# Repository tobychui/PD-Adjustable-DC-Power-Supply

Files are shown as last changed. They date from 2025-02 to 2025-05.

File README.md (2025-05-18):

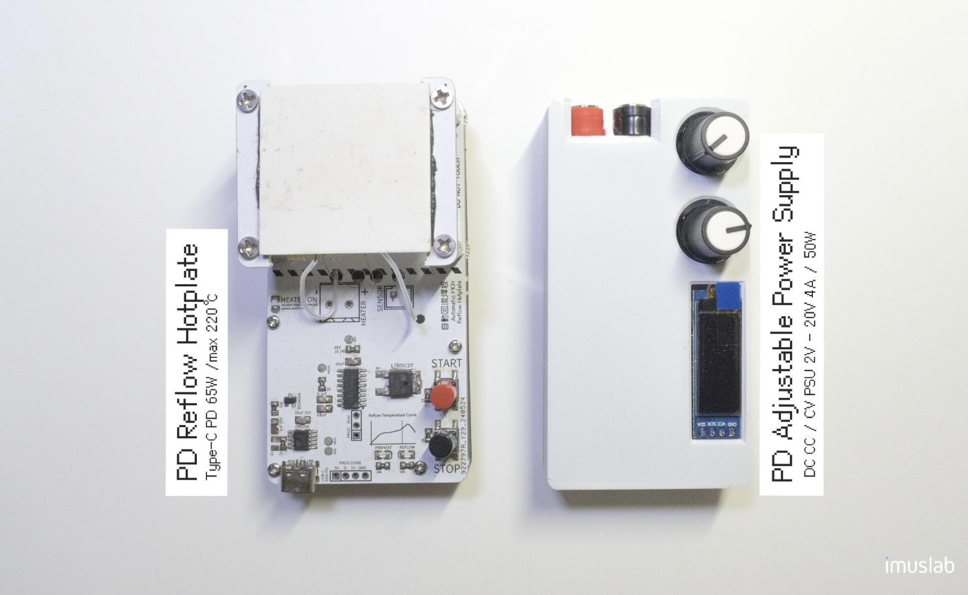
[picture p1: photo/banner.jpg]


# PD Adjustable DC Power Supply

A DIY, USB PD powered, pocket sized adjustable DC / lab bench power supply for electronic makers

I also made a pocket size reflow hotplate for automatically reflowing SMD components. See [here](https://github.com/tobychui/MCH-PD-Automatic-Reflow-Hotplate) for more details on how to build one. These two pocket size devices have the same footprint so they can be stacked in your portable tool box!

### Specifications

| Item | Value | Remarks |
| --- | --- | --- |
| Power Input | USB PD (type C) 60W at 20V 3A | Refer to CH224K datasheet for trigger specifications |
| Power Output | Adjustable DC (2V to 20V), max 4A or 50W | Refer to XL4015E datasheet for specification |
| Dimension | 10cm x 5.2cm x 1.9cm (without knobs)<br />10cm x 5.2cm x 3.3cm (with knobs) | Adj. Knobs are replaceable |
| Output Mode | Constant Voltage (CV) / Constant Current (CC) | |
| Display Size | 0.91 inch OLED | |
| Display Accuracy | +/- 0.02V and +/- 0.05A | Refresh rate @ 1Hz |
| Data Output | Real-time voltage and current usage in csv format | Can be viewed via Arduino IDE serial graph plotter |

### Photo

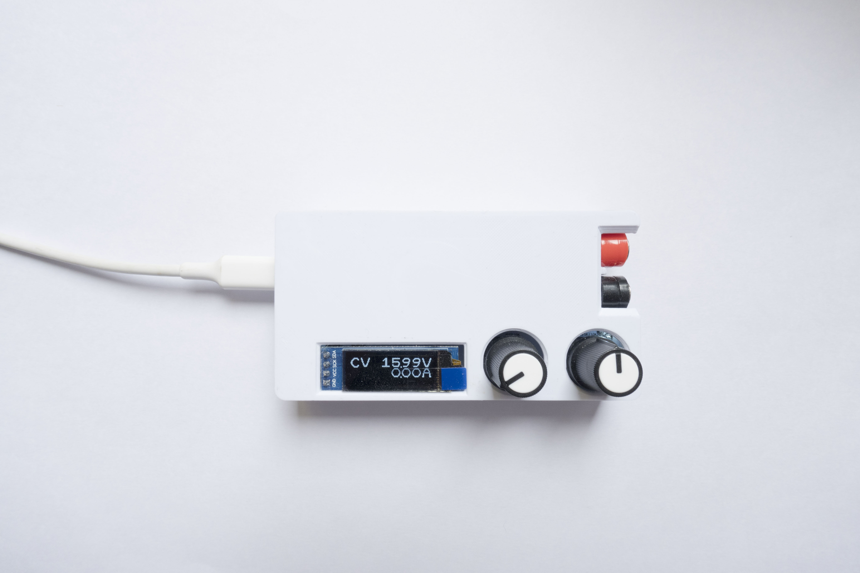
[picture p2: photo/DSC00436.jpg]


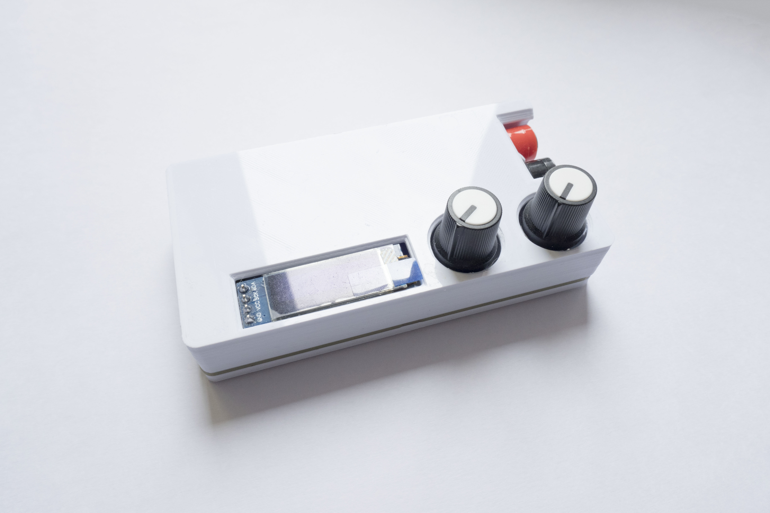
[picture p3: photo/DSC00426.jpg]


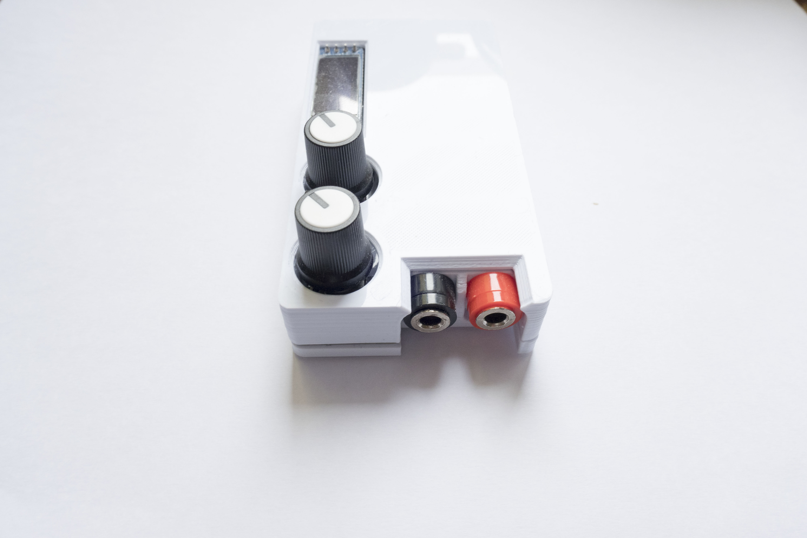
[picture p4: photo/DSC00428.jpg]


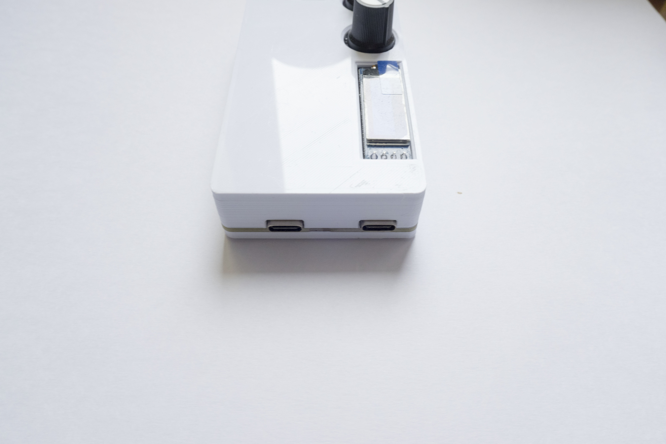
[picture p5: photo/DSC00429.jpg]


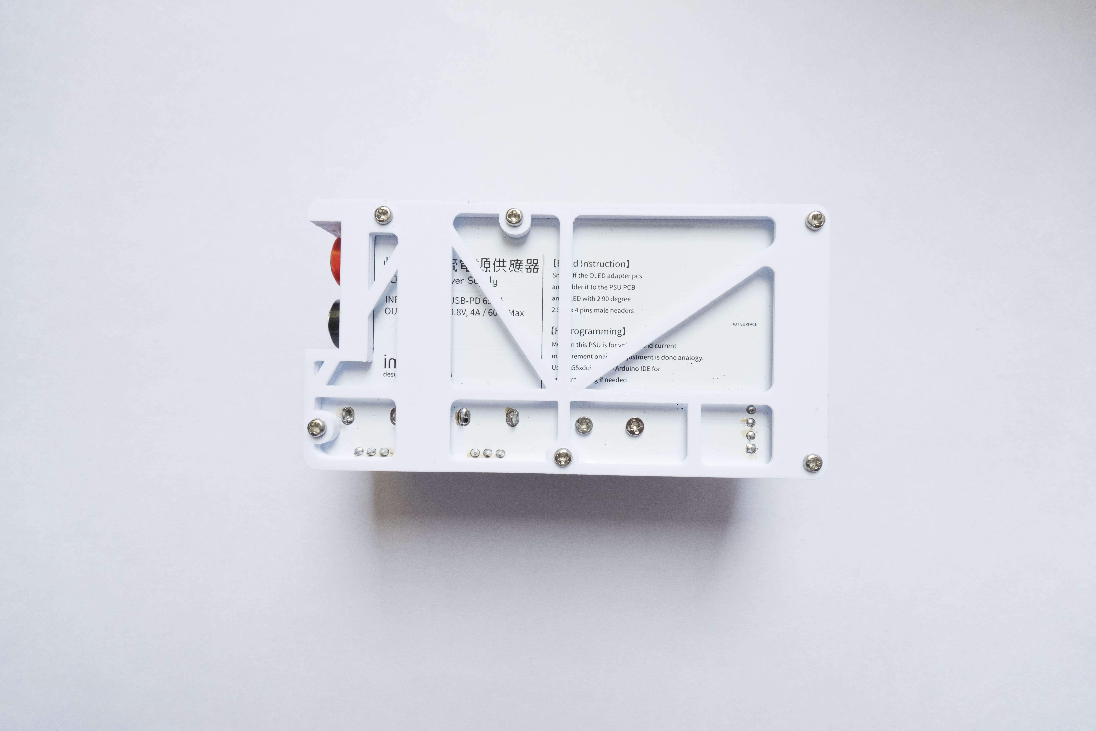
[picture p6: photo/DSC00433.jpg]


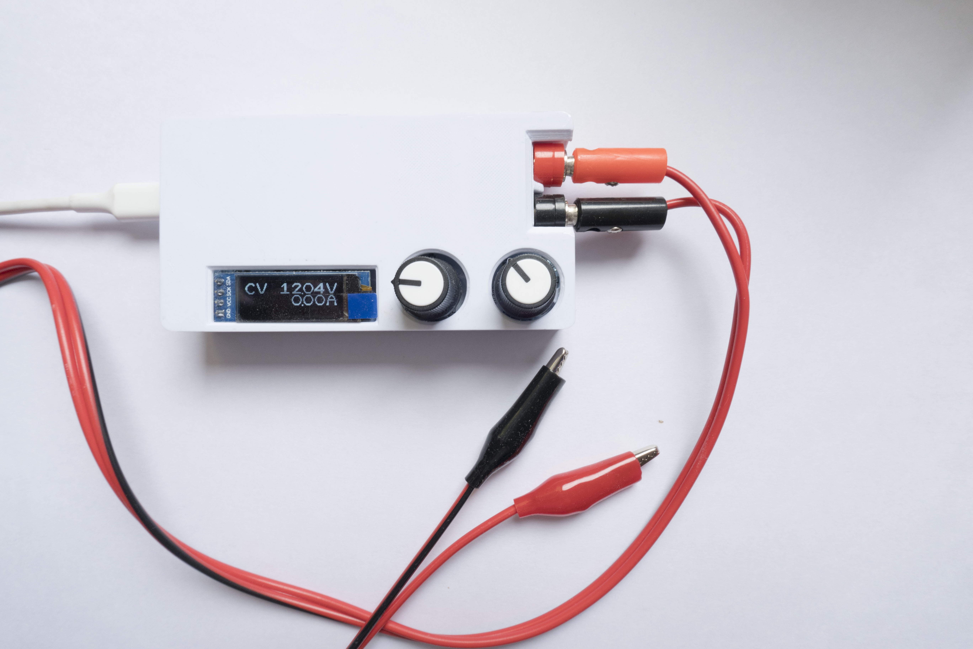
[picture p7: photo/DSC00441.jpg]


### Setting a Current Limit

Here are the steps to set the current limit on the PD power supply

1. Reduce both the output voltage and current to the lowest by rotating the knobs anticlockwise
2. Short the output positive and negative terminal. Now, the power supply should automatically switch into CC mode.
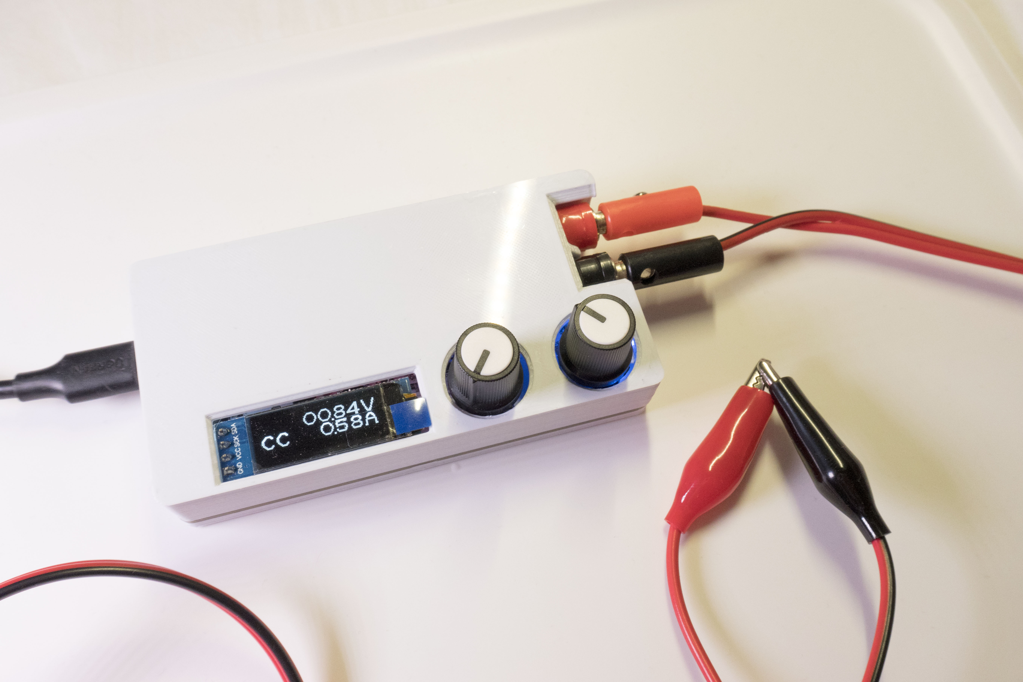
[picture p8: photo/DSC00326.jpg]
   
3. Slowly increase the current output by rotating the current knob (left knob) clockwise until a desired current is reached
4. Release the shorted terminal, now the power supply should automatically switch back to CV mode.
5. Increase the voltage until the target voltage output is reached.
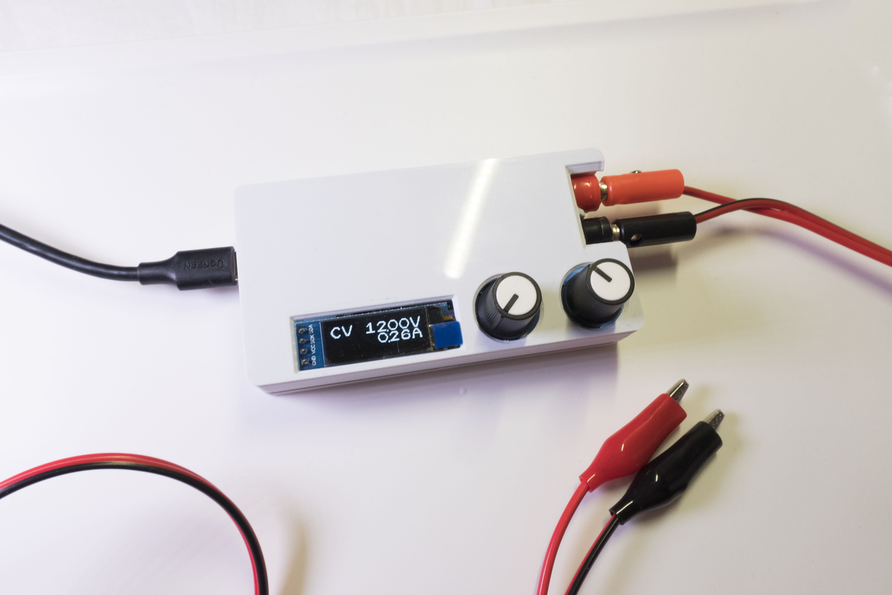
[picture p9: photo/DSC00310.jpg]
   

### Folder Structure

- Firmware: The CH552G firmware for the real time information display
- PCB: The Gerber files and EasyEDA source file (which you can generate part lists / BOM from the online editor if needed)
- 3D Model: The 3D model for the case
- Schematic: Circuit diagram & Schematic file & logic circuit analysis
- Photo: Some photo shoot of the finalized product

### Version Info

If you are planning to make one with the help of PCBA services, you can use the version 4 which is optimized for semi-PCBA manufacturing routine. 

If you are planning to DIY one from scratch (only the PCB is printed, all other parts are manually soldered), consider using reversion 5 by HCCLAB which has been optimized for manual soldering.

### Firmware Flashing

The firmware used by this PD power supply requires Arduino IDE with [CH55xduino](https://github.com/DeqingSun/ch55xduino) installed. There are no external dependencies except the above board library.

**The firmware code is designed for 0.91 inch single color OLED module running over I2C mode only**. Other display module will not work.

To flash the firmware, connect to the power supply via the lower USB port (the one closer to the display ). The CH552G has internal USB host that do not require an external USB to UART chips like CH340. If you have the CH55xduino correctly installed, your computer should detect an unknown USB device (before firmware flashing) or a virtual serial port (after firmware flashed) where you can use as a COM port to flash new firmware. 

### License

- Code: MIT
- Hardware and 3D model designs: CC BY-NC-SA

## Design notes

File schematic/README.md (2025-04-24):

# Schematic
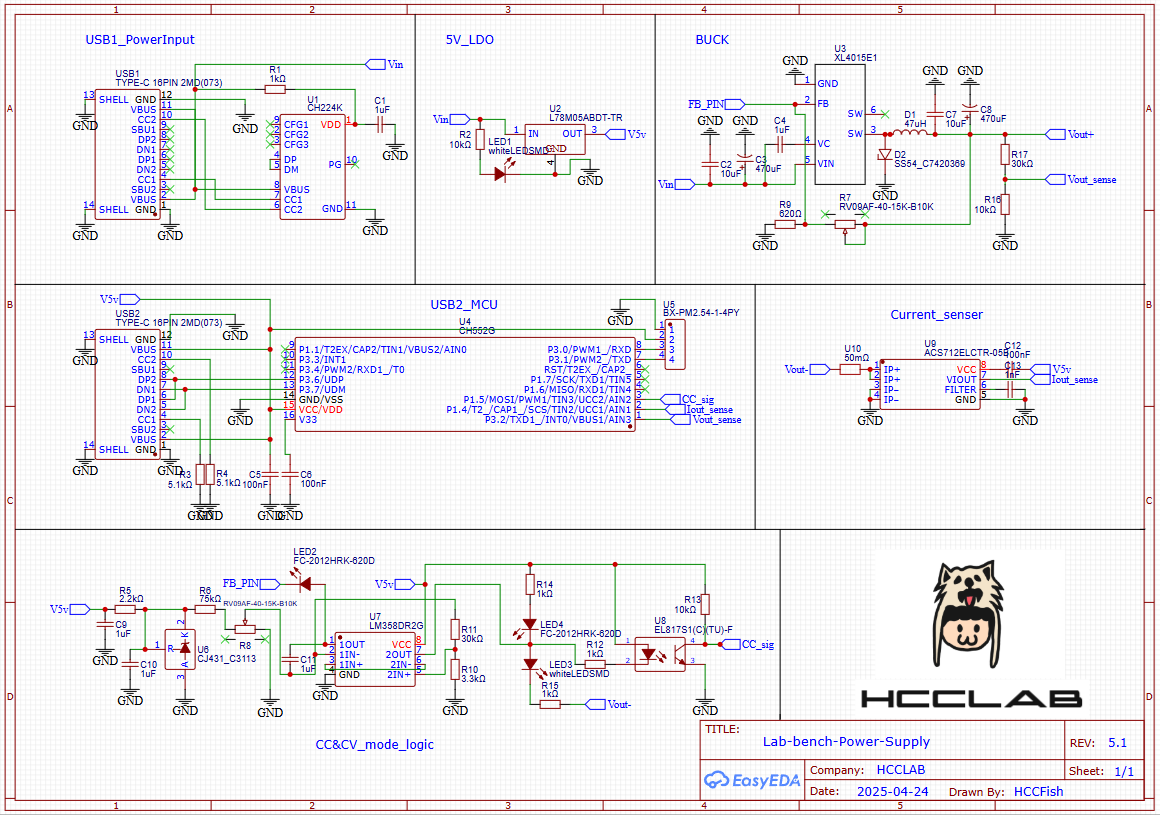
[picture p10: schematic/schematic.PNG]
Schematic Diagram


---

# Schematic draft
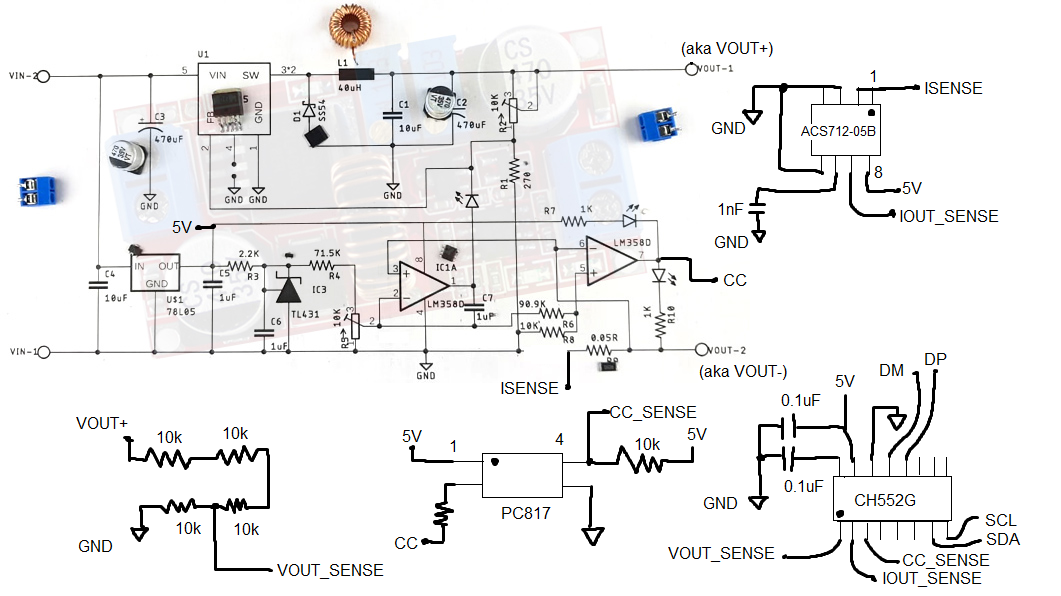
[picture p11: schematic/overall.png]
Old Schematic Diagram


---

# OpAmp Analysis

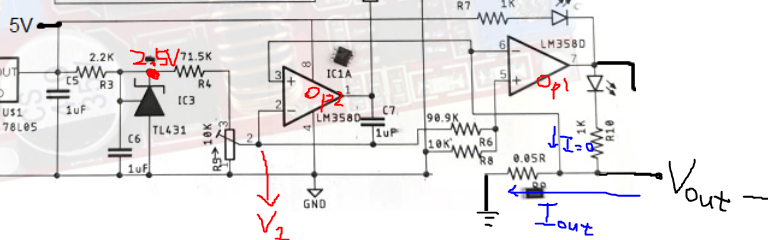
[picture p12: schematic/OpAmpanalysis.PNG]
OpAmp Analysis Diagram


> **Note:**
>
> - Vout- = Iout × 0.05 Ω  
> - 0 kΩ ≤ Rcurrent (R9) ≤ 10 kΩ  
> - V1 = 2.5 × (Rcurrent / (R4 + Rcurrent))

---

## OpAmp1 (Right Side)

### Inputs

- **Non-inverting (+):** Vout-
- **Inverting (–):** V1 × (R8 / (R6 + R8)) ≈ V1 / 10

### Output

#### Case 1: If Vout- > V1/10

- Vout- / 0.25 > (Rcurrent / (R4 + Rcurrent))
- Iout > 5 × (Rcurrent / (R4 + Rcurrent))
- **Result:** Output = 5V → Constant Current (CC) mode

#### Case 2: If Vout- < V1/10

- Vout- / 0.25 < (Rcurrent / (R4 + Rcurrent))
- Iout < 5 × (Rcurrent / (R4 + Rcurrent))
- **Result:** Output = 0V → Constant Voltage (CV) mode

---

## OpAmp2 (Left Side)

### Inputs

- **Non-inverting (+):** V1, where V1 = 2.5 × (Rcurrent / (R4 + Rcurrent))
- **Inverting (–):** Vout-

### Output

#### Case 1: If V1 > Vout-

- (Rcurrent / (R4 + Rcurrent)) > Vout- / 2.5  
- (Rcurrent / (R4 + Rcurrent)) > 0.02 × Iout)
- 50 × (Rcurrent / (R4 + Rcurrent)) > Iout
- **Result:** Output = 5V → Short

#### Case 2: If V1 < Vout-

- (Rcurrent / (R4 + Rcurrent)) < Vout- / 2.5  
- (Rcurrent / (R4 + Rcurrent)) < 0.02 × Iout)
- 50 × (Rcurrent / (R4 + Rcurrent)) < Iout
- **Result:** Output = 0V → Not short

---

## Summary

- **CC mode and Short:** When Iout > 50 × (Rcurrent / (R4 + Rcurrent))
- **CC mode and Not short:** When 50 × (Rcurrent / (R4 + Rcurrent)) > Iout > 5 × (Rcurrent / (R4 + Rcurrent))
- **CV mode and Not short:** When Iout < 5 × (Rcurrent / (R4 + Rcurrent))

> **Notice:**  
> Due to the finite open-loop gain and input offset voltage, the circuit does not behave ideally, resulting in some deviation.

---

## Example Calculation

Assume the following values:  
- R4 = 75K  
- Maximum Rcurrent = 10K

1. **Calculate the ratio:**  
   Ratio = Rcurrent / (R4 + Rcurrent) = 10K / (75K + 10K) = 10/85 ≈ 0.1176

2. **Determine the thresholds for Iout:**
   - **CC mode and Short:**  
     Iout > 50 × 0.1176 ≈ 5.88  
   - **CC mode and Not short:**  
     5.88 > Iout > 5 × 0.1176 ≈ 0.588  
   - **CV mode and Not short:**  
     Iout < 0.588

These threshold values illustrate how the circuit behavior changes based on the output current when R4 is 75K and the maximum Rcurrent is 10K.

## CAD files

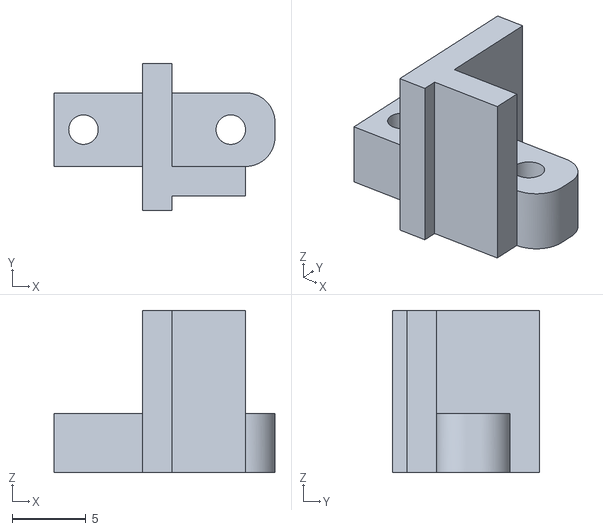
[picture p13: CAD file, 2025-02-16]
3D model/v4/oled_support.stl
15.0 x 10.0 x 11.0

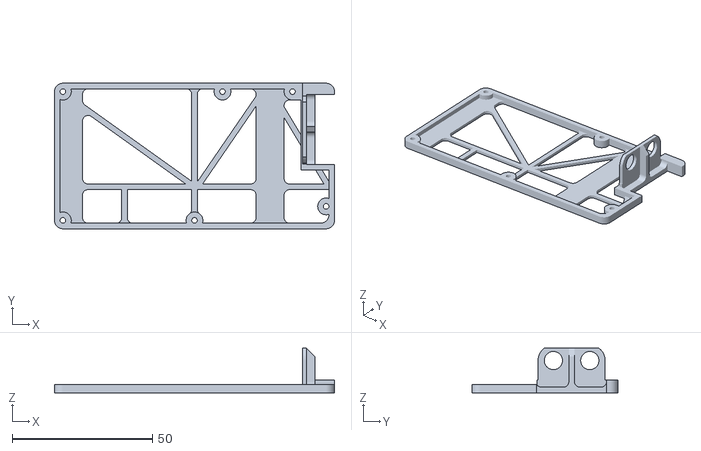
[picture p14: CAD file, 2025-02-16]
3D model/v4/bottom v3 squr.stl
100.0 x 52.0 x 15.9

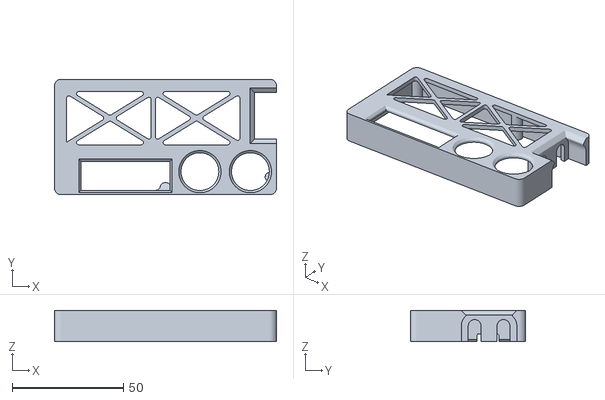
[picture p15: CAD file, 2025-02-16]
3D model/v4/top_squr.stl
100.0 x 52.0 x 14.0

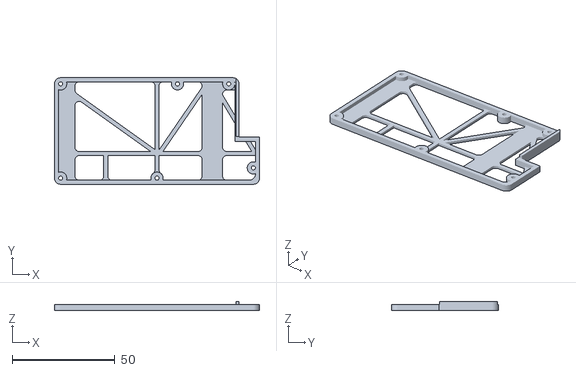
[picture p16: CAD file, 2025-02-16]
3D model/v4/bottom v2.stl
100.0 x 52.0 x 4.50

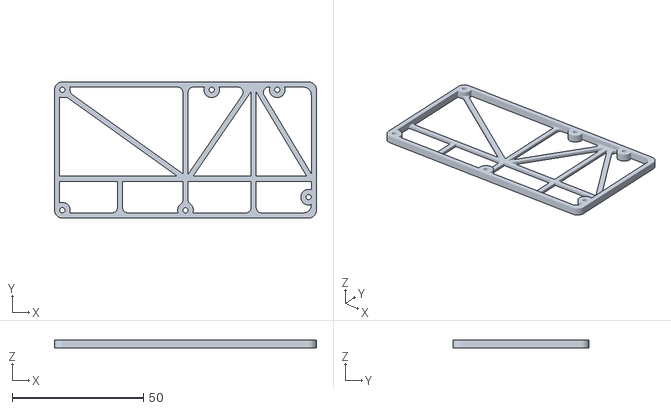
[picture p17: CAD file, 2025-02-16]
3D model/v4/bottom.stl
100.0 x 52.0 x 3.00

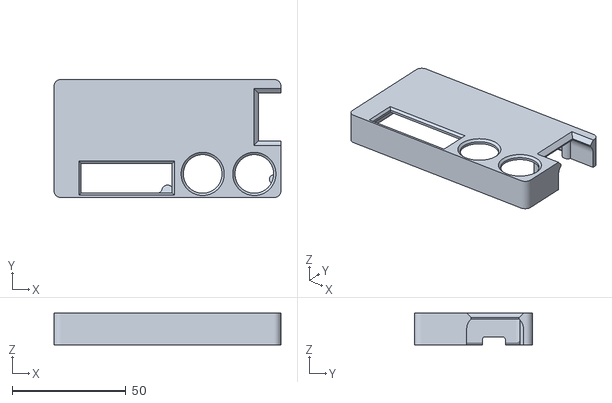
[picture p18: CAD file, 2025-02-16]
3D model/v4/top_squr_v3.stl
100.0 x 52.0 x 14.0

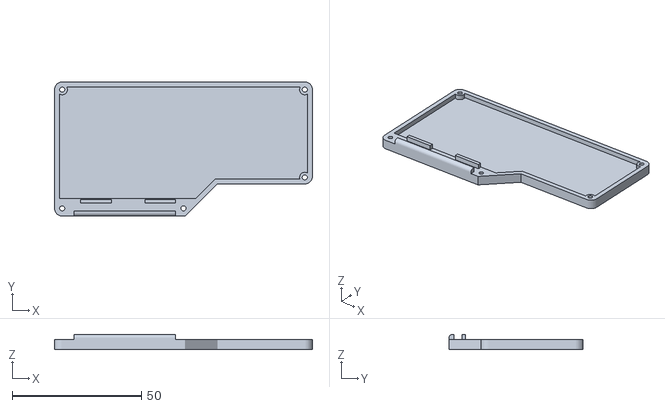
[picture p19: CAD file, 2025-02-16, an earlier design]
3D model/v1/power-supply_bottom v3.stl
100.0 x 52.0 x 6.00

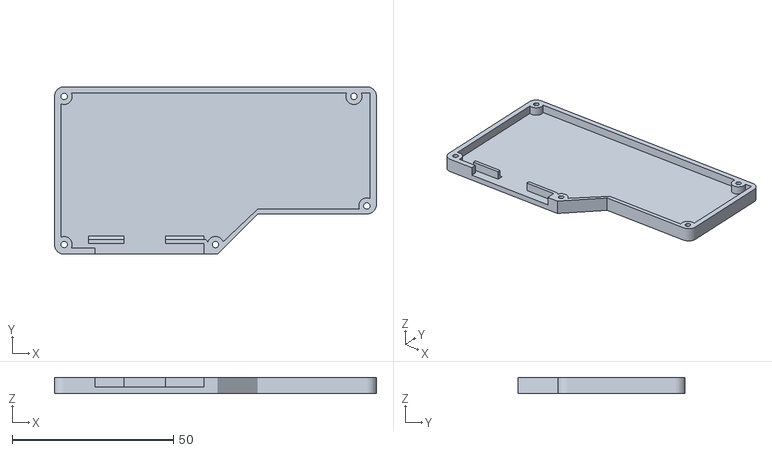
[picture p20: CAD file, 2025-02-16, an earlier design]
3D model/v2/bottom.stl
100.0 x 52.0 x 5.00

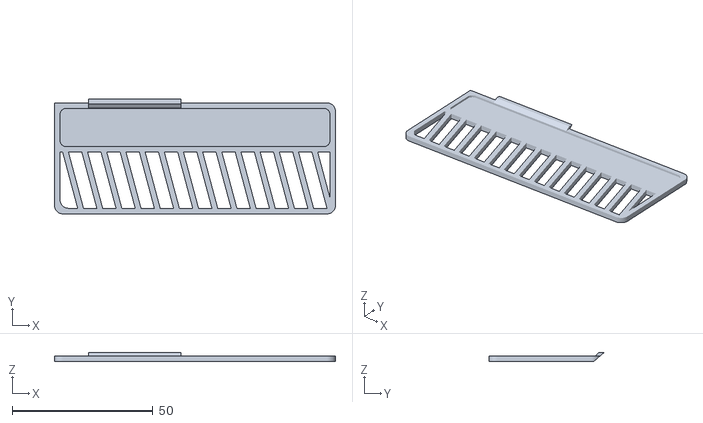
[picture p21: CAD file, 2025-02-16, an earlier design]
3D model/v3/top rev5 part2.stl
100.0 x 40.9 x 3.30

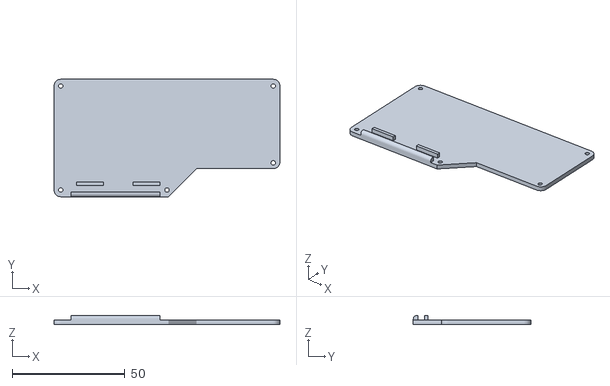
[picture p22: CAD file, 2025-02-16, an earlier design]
3D model/v1/power-supply_bottom v1.stl
100.0 x 52.0 x 4.00

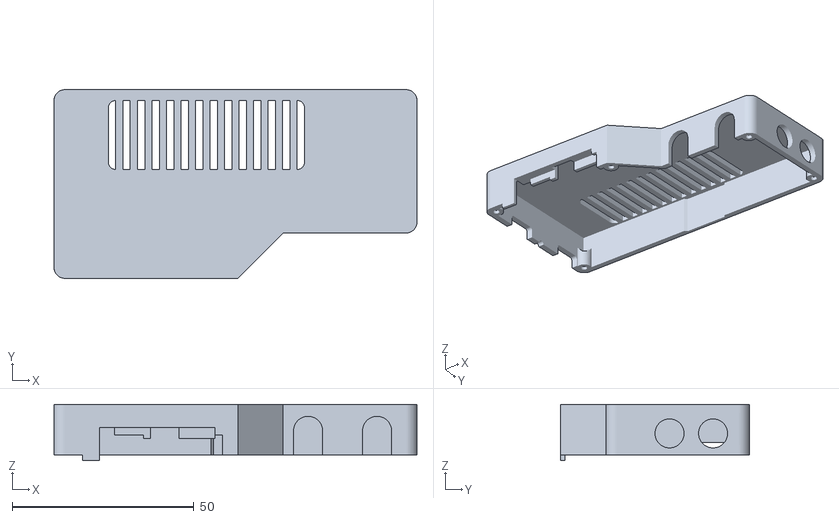
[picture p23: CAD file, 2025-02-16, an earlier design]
3D model/v2/top.stl
100.0 x 52.0 x 15.5

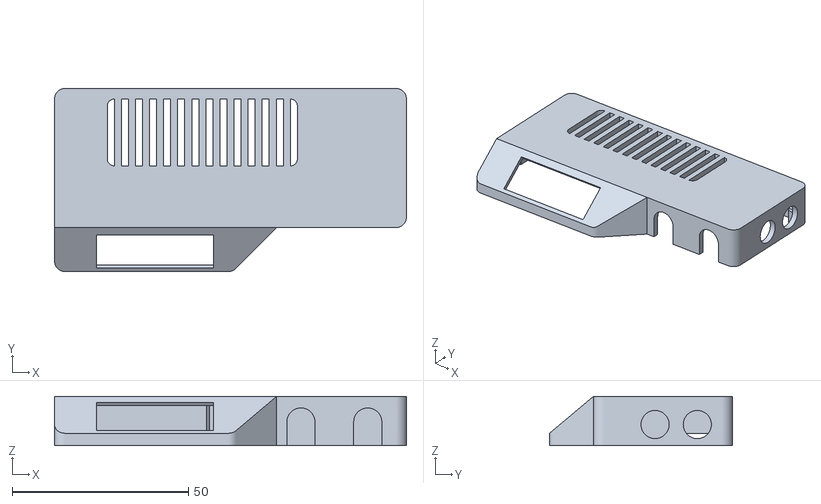
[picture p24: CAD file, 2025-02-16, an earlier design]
3D model/v3/top.stl
100.0 x 52.0 x 14.0

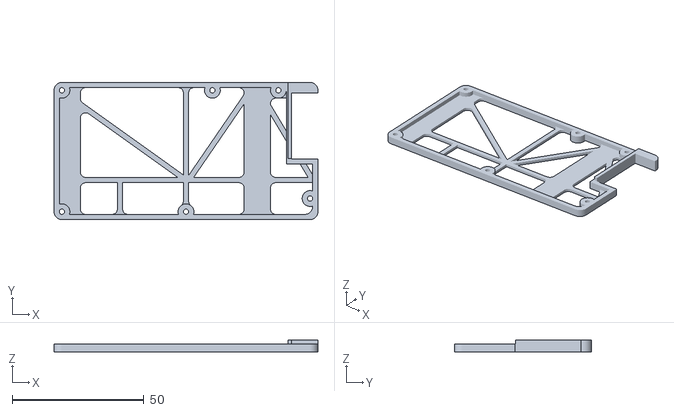
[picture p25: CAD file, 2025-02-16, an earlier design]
3D model/v4/bottom v2 squr.stl
100.0 x 52.0 x 4.50

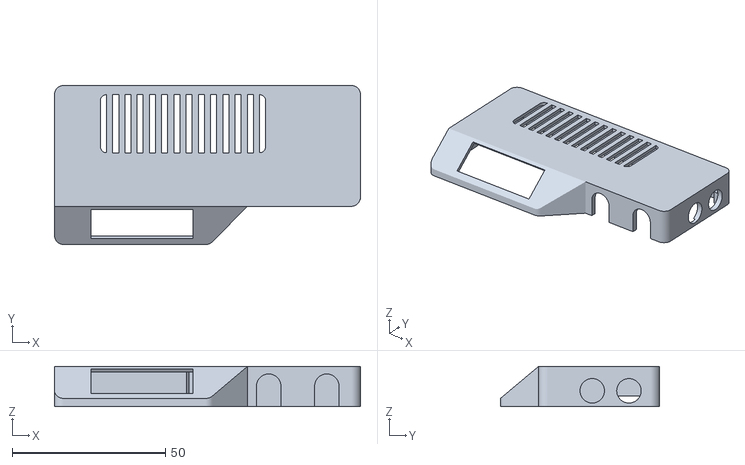
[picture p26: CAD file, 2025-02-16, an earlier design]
3D model/v3/top rev2.stl
100.0 x 52.0 x 13.2

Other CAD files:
3D model/v4/top.stl
3D model/v1/power-supply_top v4.stl
3D model/v3/bottom.stl
3D model/v3/top rev3.stl
3D model/placeholder/OLED 128 x 32 Display Assembly.ipt
3D model/v2/OldVersions/bottom.0012.ipt
3D model/v2/OldVersions/display_mount.0001.ipt
3D model/v2/OldVersions/pcb_mockup.0001.ipt
3D model/v2/OldVersions/test-fit.0007.iam
3D model/v2/OldVersions/top.0036.ipt
3D model/v2/bottom.ipt
3D model/v2/pcb_mockup.ipt
3D model/v2/test-fit.iam
3D model/v2/top.ipt
3D model/v3/OldVersions/bottom rev3.0006.ipt
3D model/v3/OldVersions/bottom rev4.0008.ipt
3D model/v3/OldVersions/bottom.0025.ipt
3D model/v3/OldVersions/display_mount.0005.ipt
3D model/v3/OldVersions/pcb_mockup.0001.ipt
3D model/v3/OldVersions/test-fit rev2.0006.iam
3D model/v3/OldVersions/test-fit.0011.iam
3D model/v3/OldVersions/top rev2.0056.ipt
3D model/v3/OldVersions/top rev3.0005.ipt
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

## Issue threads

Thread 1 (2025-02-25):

Wrong value of resistor in schematic

indexdb, 2025-02-25:
some registers value  in schematic are different with BOM from pcb

tobychui, 2025-02-25:
I didn't draw a proper schematic for this project, so the BOM from the PCB is not correct (I only use the footprint from the library, regardless of the component values). Please follow the value on the silkscreen or the schematic instead.

indexdb, 2025-02-25:
The values from schematic are different between from silkscreen of pcb. For example  R4.

tobychui, 2025-02-25:
@indexdb We are still optimizing it for mass manufacturing, so the value in each PCB Gerber might differ a bit and that is normal.

The schematic is drawn from my first working prototype, you can try to figure out the value yourself by referencing the data sheet of the ICs used and your preference on sensitivity and voltage range.

Closed 2025-02-25.

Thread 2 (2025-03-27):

?ASlink-Error-Insufficient ROM/EPROM/FLASH memory.

indexdb, 2025-03-27:
Linking everything together...
"C:\\Users\\xxx\\AppData\\Local\\Arduino15\\packages\\CH55xDuino\\tools\\MCS51Tools\\2023.10.10/win/busybox" ash "C:\\Users\\xxx\\AppData\\Local\\Arduino15\\packages\\CH55xDuino\\tools\\MCS51Tools\\2023.10.10/wrapper/sdcc-link.sh" "C:\\Users\\xxx\\AppData\\Local\\Arduino15\\packages\\CH55xDuino\\tools\\sdcc\\build.13407_4/bin/sdcc" --nostdlib "-LC:\\Users\\xxx\\AppData\\Local\\Temp\\arduino_build_705067" "-LC:\\Users\\xxx\\AppData\\Local\\Arduino15\\packages\\CH55xDuino\\tools\\sdcc\\build.13407_4/lib/large_int_calc_stack_auto" --code-size 14336 --xram-size 876 --xram-loc 148 -mmcs51 -DCH552 "C:\\Users\\xxx\\AppData\\Local\\Temp\\arduino_build_705067\\sketch\\pd-psu_v3.ino.cpp.o" "C:\\Users\\xxx\\AppData\\Local\\Temp\\arduino_build_705067\\libraries\\SoftI2C\\SoftI2C.c.o" "C:\\Users\\xxx\\AppData\\Local\\Temp\\arduino_build_705067\\libraries\\SoftI2C\\wireStyleWrapper.c.o" "C:\\Users\\xxx\\AppData\\Local\\Temp\\arduino_build_705067/..\\arduino_cache_333092\\core\\core_037c3206115b3f8e44bae137ed0b2b39.a" -lmcs51 -llibsdcc -lliblong -lliblonglong -llibint -llibfloat --out-fmt-ihx -o "C:\\Users\\xxx\\AppData\\Local\\Temp\\arduino_build_705067/pd-psu_v3.ino.elf"

**?ASlink-Error-Insufficient ROM/EPROM/FLASH memory.**
"C:\\Users\\xxx\\AppData\\Local\\Arduino15\\packages\\CH55xDuino\\tools\\sdcc\\build.13407_4/bin/avr-objcopy_7_3_0" -O ihex -R DATA -R INITIALIZED -R SSEG "C:\\Users\\xxx\\AppData\\Local\\Temp\\arduino_build_705067/pd-psu_v3.ino.elf" "C:\\Users\\xxx\\AppData\\Local\\Temp\\arduino_build_705067/pd-psu_v3.ino.hex"
C:\Users\xxx\AppData\Local\Arduino15\packages\CH55xDuino\tools\sdcc\build.13407_4/bin/avr-objcopy_7_3_0: 'C:\Users\xxx\AppData\Local\Temp\arduino_build_705067/pd-psu_v3.ino.elf': No such file
使用 1.0  版本的库 SoftI2C 在文件夹： C:\Users\xxx\AppData\Local\Arduino15\packages\CH55xDuino\hardware\mcs51\0.0.25\libraries\SoftI2C
exit status 1
为开发板 CH552 Board 编译时出错。

tobychui, 2025-03-27:
@HCCFish I remember you have encountered this same issue before, how you eventually solved this?

HCCFish, 2025-03-27:
This happened because the CH552 only has 16KB of code flash, and we're trying to fit the display driver into it. Although we didn't exceed the maximum program storage limit, the Arduino IDE can sometimes be unstable.

Here's how I solved it:
-  Go to the Board Manager and downgraded the CH55xDuino version to 0.0.22.

Closed 2025-05-17.

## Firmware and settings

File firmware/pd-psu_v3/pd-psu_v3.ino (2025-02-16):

/*
    PD Power Supply
    Author: 

    This is the firmware for the PD power supply 
    that reads the voltage and current of the supply and display the 
    power information on the SSD1306 OLED display.

    This firmware is designed for CH552G with CH55xduino board definations
    Recommend config
    24Mhz (Internal), 5V

*/
#include <Serial.h>

/* Hardware Definations */
#define CURRENT_PIN 14  //0 - 5A
#define VOLTAGE_PIN 32  //0 - 20V
#define CCCV_PIN 15     //CC = LOW, CV = HIGH
#define OLED_SCL 30
#define OLED_SDA 31

/* Global Variables */
uint16_t voltageReading;
uint16_t currentReading;
bool isCCMode;

/* Function Prototypes */
void setupOLED();
void initializeOLED();
void clearScreen();
void PS_Screen(uint16_t, uint16_t, bool);

void setup() {
  //Disable internal pull-up resistors for input pins
  pinMode(CURRENT_PIN, INPUT);
  pinMode(VOLTAGE_PIN, INPUT);
  pinMode(CCCV_PIN, INPUT);

  // Initialize I2C pins for OLED
  setupOLED();
  initializeOLED();

  //Clear the OLED screen
  clearScreen();
}

void loop() {
  //Get Output Voltage
  voltageReading = 0;
  for (int i = 0; i < 10; i++) {
    voltageReading += map(analogRead(VOLTAGE_PIN), 0, 255, 0, 500) * 4;  //Convert ADC to Volt
  }

  //Get output current
  currentReading = analogRead(CURRENT_PIN);
  currentReading = (((float)currentReading * (5.0 / 255.0)) - 2.5) / 0.185 * 100;  //Max range -5A to 5A
  isCCMode = !digitalRead(CCCV_PIN);

  //Cap the range of digits to make sure it won't overflow
  voltageReading = min(voltageReading, 99999);
  currentReading = min(currentReading, 999);

  //Print result on USB Serial
  USBSerial_print(((float)voltageReading / 1000));
  USBSerial_print(",");
  USBSerial_println(((float)currentReading / 100));

  //Update OLED display
  PS_Screen(voltageReading/10, currentReading, isCCMode);
}

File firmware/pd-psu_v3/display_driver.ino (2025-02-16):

#include <SoftI2C.h>
#include "display_char.h"

// Address of the I2C OLED
#define OLED_I2C_ADDRESS 0x3C

// Commands for SSD1306
#define SSD1306_DISPLAYOFF 0xAE
#define SSD1306_SETDISPLAYCLOCKDIV 0xD5
#define SSD1306_SETMULTIPLEX 0xA8
#define SSD1306_SETDISPLAYOFFSET 0xD3
#define SSD1306_SETSTARTLINE 0x40
#define SSD1306_CHARGEPUMP 0x8D
#define SSD1306_MEMORYMODE 0x20
#define SSD1306_SEGREMAP 0xA1
#define SSD1306_COMSCANDEC 0xC8
#define SSD1306_SETCOMPINS 0xDA
#define SSD1306_SETCONTRAST 0x81
#define SSD1306_SETPRECHARGE 0xD9
#define SSD1306_SETVCOMDETECT 0xDB
#define SSD1306_DISPLAYALLON_RESUME 0xA4
#define SSD1306_NORMALDISPLAY 0xA6
#define SSD1306_DISPLAYON 0xAF

//Global Variables
static uint16_t display_num[10][16] = display16X16_number_R;
static uint16_t display_A[16] = display16X16_A_R;
static uint16_t display_C[16] = display16X16_C_R;
static uint16_t display_V[16] = display16X16_V_R;
static uint16_t display_blank[16] = display16X16_blank;
uint8_t voltage_dec_3;
uint8_t voltage_dec_2;
uint8_t voltage_dec_1;
uint8_t voltage_dec_0;
uint8_t current_dec_2;
uint8_t current_dec_1;
uint8_t current_dec_0;
uint16_t* display_addr_list[16];

void I2CWriteCommand(uint8_t command) {
  I2CStart();
  I2CSend(OLED_I2C_ADDRESS << 1);  // I2C address + Write bit
  I2CSend(0x00);                   // Co = 0, D/C# = 0
  I2CSend(command);
  I2CStop();
}

void I2CWriteData(uint8_t data) {
  I2CStart();
  I2CSend(OLED_I2C_ADDRESS << 1);  // I2C address + Write bit
  I2CSend(0x40);                   // Co = 0, D/C# = 1
  I2CSend(data);
  I2CStop();
}

//Setup the OLED SoftI2C Config, call to initializeOLED to start connection
void setupOLED() {
  scl_pin = OLED_SCL;  // Default: P3.0
  sda_pin = OLED_SDA;  // Default: P3.1
  I2CInit();

  //Setup static locations for display array
  display_addr_list[2] = display_blank;
  display_addr_list[7] = display_V;
  display_addr_list[10] = display_blank;
  display_addr_list[11] = display_blank;
  display_addr_list[15] = display_A;
}

//Start the OLED screen in desired mode
void initializeOLED() {
  I2CWriteCommand(SSD1306_DISPLAYOFF);
  I2CWriteCommand(SSD1306_SETDISPLAYCLOCKDIV);
  I2CWriteCommand(0x80);  // Suggested value
  I2CWriteCommand(SSD1306_SETMULTIPLEX);
  I2CWriteCommand(0x3F);
  I2CWriteCommand(SSD1306_SETDISPLAYOFFSET);
  I2CWriteCommand(0x00);
  I2CWriteCommand(SSD1306_SETSTARTLINE | 0x0);
  I2CWriteCommand(SSD1306_CHARGEPUMP);
  I2CWriteCommand(0x14);
  I2CWriteCommand(SSD1306_MEMORYMODE);
  I2CWriteCommand(0x00);
  I2CWriteCommand(SSD1306_SEGREMAP | 0x1);
  I2CWriteCommand(SSD1306_COMSCANDEC);
  I2CWriteCommand(SSD1306_SETCOMPINS);
  I2CWriteCommand(0x12);
  I2CWriteCommand(SSD1306_SETCONTRAST);
  I2CWriteCommand(0xCF);
  I2CWriteCommand(SSD1306_SETPRECHARGE);
  I2CWriteCommand(0xF1);
  I2CWriteCommand(SSD1306_SETVCOMDETECT);
  I2CWriteCommand(0x40);
  I2CWriteCommand(SSD1306_DISPLAYALLON_RESUME);
  I2CWriteCommand(SSD1306_NORMALDISPLAY);
  I2CWriteCommand(SSD1306_DISPLAYON);
}

//Clear the screen with setting all bits to 0
void clearScreen() {
  for (uint8_t i = 0; i < 8; i++) {
    I2CWriteCommand(0xB0 + i);  // Set page address
    I2CWriteCommand(0x00);      // Set lower column address
    I2CWriteCommand(0x10);      // Set higher column address
    for (uint8_t j = 0; j < 128; j++) {
      I2CWriteData(0x00);
    }
  }
}

//Clear the screen with setting all bits to 1
void lightScreen() {
  for (uint8_t i = 0; i < 8; i++) {
    I2CWriteCommand(0xB0 + i);  // Set page address
    I2CWriteCommand(0x00);      // Set lower column address
    I2CWriteCommand(0x10);      // Set higher column address
    for (uint8_t j = 0; j < 128; j++) {
      I2CWriteData(0xFF);
    }
  }
}

//Print the current power information to the screen
void PS_Screen(uint16_t voltage_num, uint16_t current_num, bool CC_mode) {
  voltage_dec_3 = (voltage_num / 1000) % 10;
  voltage_dec_2 = (voltage_num / 100) % 10;
  voltage_dec_1 = (voltage_num / 10) % 10;
  voltage_dec_0 = voltage_num % 10;
  current_dec_2 = (current_num / 100) % 10;
  current_dec_1 = (current_num / 10) % 10;
  current_dec_0 = current_num % 10;
  if (!CC_mode) {
    display_addr_list[0] = display_C;
    display_addr_list[1] = display_V;
    display_addr_list[8] = display_blank;
    display_addr_list[9] = display_blank;
  } else {
    display_addr_list[0] = display_blank;
    display_addr_list[1] = display_blank;
    display_addr_list[8] = display_C;
    display_addr_list[9] = display_C;
  }
  display_addr_list[3] = display_num[voltage_dec_3];
  display_addr_list[4] = display_num[voltage_dec_2];
  display_addr_list[5] = display_num[voltage_dec_1];
  display_addr_list[6] = display_num[voltage_dec_0];
  display_addr_list[12] = display_num[current_dec_2];
  display_addr_list[13] = display_num[current_dec_1];
  display_addr_list[14] = display_num[current_dec_0];
  
  uint8_t push_temp;
  uint8_t readed_byte;
  for (uint8_t i = 0; i < 8; i++) {
    //Set editing page number
    I2CStart();
    I2CSend(OLED_I2C_ADDRESS << 1);  // I2C address + Write bit
    I2CSend(0xB0 + i);               // Set page address
    //I2CSend(0x00);      // Set lower column address
    //I2CSend(0x10);      // Set higher column address
    //Start sending page data
    I2CRestart();
    I2CSend(OLED_I2C_ADDRESS << 1);  // I2C address + Write bit
    I2CSend(0x40);                   // Co = 0, D/C# = 1
    for (uint8_t j = 0; j < 128; j++) {
      if (i % 4 == 3 && (j == 79 || j == 80)) {
        I2CSend(0xA0);
      } else {
        push_temp = 0;
        readed_byte = display_addr_list[(j >> 4) + (i / 4 * 8)][j % 16] >> (i % 4 << 2);
        push_temp |= ((readed_byte >> 3) & 0x01) << 7;
        push_temp |= ((readed_byte >> 2) & 0x01) << 5;
        push_temp |= ((readed_byte >> 1) & 0x01) << 3;
        push_temp |= (readed_byte & 0x01) << 1;
        I2CSend(push_temp);
      }
    }
    I2CStop();
  }
}

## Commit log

2025-02-16 init commit
    [OLED 128 x 32 Display Assembly.ipt, bottom rev2.ipt, bottom rev2.stl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]
2025-02-16 Change the component for PCBA
2025-02-27 Modify parts for better production and assembly.
2025-03-06 Revert "update readme.md"
    This reverts commit 7bf3034ea4b36c089612d9dcf4a17087f916551d.
    [pd-psu_v3.ino]
2025-03-13 Change R4 resister to fix low output current error.
2025-03-13 add schematic/README.md
2025-04-24 Add new schematic
2025-04-24 Add schematic file
